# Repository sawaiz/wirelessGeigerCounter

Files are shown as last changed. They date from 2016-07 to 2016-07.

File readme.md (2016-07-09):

# Wireless Geiger Counter
A distributed radiation detection networks requires a low power, rugged, portable, and wireless detection modules. These prototypes are housed in a plastic shell allowing them to be made waterproof, transmit data over Wi-Fi allowing them to be placed anywhere you can host a network, and are designed to last for months from a single charge. A Geiger tube provides the signal that is read in by a microcontroller that then transmits the counts to a database.



## Hardware
A single board that hosts the electronics required to take power from a lithium ion cell, provide the bias voltage required by the Geiger tube (new old stock Russian SBM-20), and transmit that data over Wi-Fi.

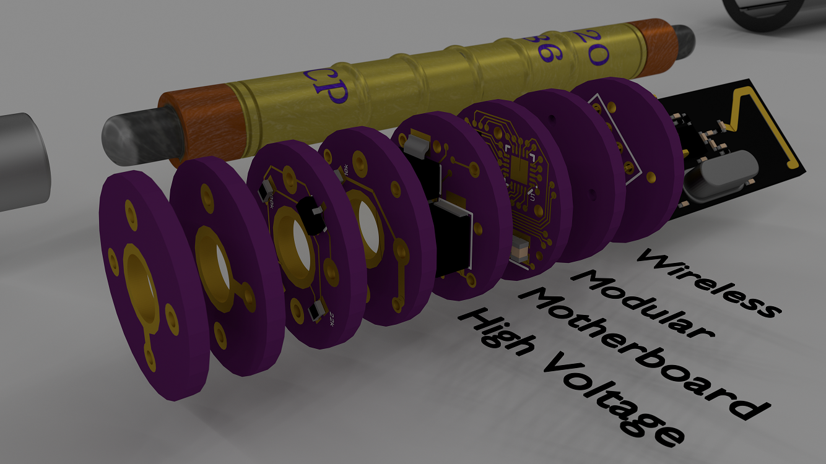
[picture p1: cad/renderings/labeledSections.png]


### Power
The power to the module is provided through a 18650 Li-ion chemistry cell. This is a rechargeable cell that is very common (used in laptop batteries, Tesla vehicles, and LED flashlights) with a capacity of 1.5Ah - 3.4Ah. The battery has a management circuit that prevents over/under voltage and allows charging. It also provides fuel gauging to the microcontroller. The rest of the board is supplied a regulated 3.3V.

### Wireless
The espressif module has a on board antenna although a chip antenna can be substituted. The Wi-Fi using the on board antennas on a ESP-12F module is shown to have a range of at least 250m with almost a km under ideal conditions. It is able to connect on 802.11 b/g/n with a maximum data rate of 150Mbps.

### Microcontroller
The ESP8266/ESP8285 has a integrated Tensilica L106 Diamond series 32-bit processor running at 80Mhz. The 12E/F module breaks out the 13 GPIO pins and one 10-bit ADC. Some of those pins are reserved for communication to storage, and wake from deep sleep. The pins are not 5V tolerant and average current consumption, including connection to Wi-Fi is 80mA, though peaks currents approach 500mA for short (<5ms) bursts.

### High voltage
The high voltage section is a Schmitt-trigger oscillator based boost converter feeding a Cockcroft-Walton voltage multiplier with the output divided and taken to a op-amp comparing against a voltage reference. The previous design used the microcontroller to boost the voltage, but that resulted in a 80mA constant current draw as the microcontroller could not be taken to deep sleep with the PWM running. The design was adapted from the following [application note](https://www.maximintegrated.com/en/app-notes/index.mvp/id/3757) form Maxim.

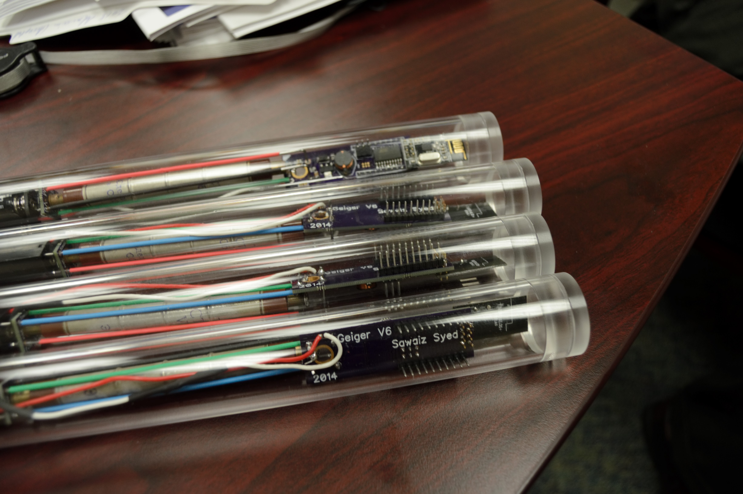
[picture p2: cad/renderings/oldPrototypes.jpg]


## Software
The software only resides on the microcontroller, and can be found [here](https://github.com/Sawaiz/geigerControl). The other required part is a SQL database to transmit the information to.

[oldPrototypes]: cad/renderings/oldPrototypes.jpg "Older prototypes"
[assembledTube]: cad/renderings/assembledTube.png "Fully Assembled Tube"
[labeledSections]: cad/renderings/labeledSections.png "Assembled Tube"

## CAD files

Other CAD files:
cad/Housing/Acrylic Tube Housing.dwg
3D/Inventor/.75in PVC.ipt
3D/Inventor/Housing/.75in PVC.ipt
Hardware/Transmitter 3D/Blender/Transmitter.blend
Hardware/Transmitter 3D/Inventor/Radiation Dector/.75in PVC.ipt
Transmitter 3D/Inventor/Radiation Dector/.75in PVC.ipt
cad/2.54 Breakaway/1x1.iam
cad/2.54 Breakaway/1x10.iam
cad/2.54 Breakaway/1x2 Angle.iam
cad/2.54 Breakaway/2x3.iam
cad/2.54 Breakaway/2x4.iam
cad/2.54 Breakaway/4x2 Angle.iam
cad/2.54 Breakaway/Holder.ipt
cad/2.54 Breakaway/OldVersions/1x2 Angle.0001.iam
cad/2.54 Breakaway/OldVersions/2x3.0001.iam
cad/2.54 Breakaway/OldVersions/Pin.0001.ipt
cad/2.54 Breakaway/OldVersions/PinRight1.0003.ipt
cad/2.54 Breakaway/OldVersions/PinRight2.0005.ipt
cad/2.54 Breakaway/Pin.ipt
cad/2.54 Breakaway/PinRight1.ipt
cad/2.54 Breakaway/PinRight2.ipt
cad/Housing/.75in PVC.ipt
cad/Housing/8907K48 045 Phosphate Rod.ipt
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

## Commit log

2014-04-12 Re-organaised and Consolidated from older repositories
    [Transmitter.blend]
2014-07-18 Reorganised software
    [Board.gbr, BoardOutline.gbr, Bottom.gbr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]
2014-07-19 organised 3d Model Folder
    [Transmitter.blend]
2014-07-24 Added BOM and Future Revisions
    [1x10.stp, BOM.xlsx]
2014-09-20 A lot of changes mostly new Board iterations.
    [BOM.xlsx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]
2014-10-15 I should be committing more frequently. Finally have a readme though.
    [BOM.xlsx]
2014-10-18 A lot of 3d work, No textures Yet.
    [0805 Resistor.0002.ipt, 0805 Resistor.ipt, 18650.ipt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]
2014-10-18 Raspberry Pi RX works, on first try, only explanation, witchery.
2014-10-19 Motherboard routed.
    [1x2 Angle.0001.iam, 1x2 Angle.iam, 4x2 Angle.iam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]
2014-10-20 Mk..7 Is born, 3d is done as well, BOM, coming soon.
    [.75in PVC.ipt, 10118194.ipt, DF40C(2.5)-20DS-0.4V.ipt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]
2014-10-28 Finalized 3d model, Organization, Presentation and poster.
    [2x4.iam, NRF24L01.ipt, NRF24L01P.ipt]
2015-02-17 TX and RX software for V6 finalised
    3d hardware models added for acrylic housing, rPiRx software, and 1975
    software for avr.
    [Acrylic Housing.0002.iam, Acrylic Housing.iam, Acrylic Tube Housing.0004.ipt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]
2015-09-09 Software moved to RadSens Repo https://github.com/aaronwoychek/RadSens
    [rPiRx.sdf]
2015-09-09 Deleted files, cleaning up
    [.75in PVC.ipt, 0805 Resistor.0002.ipt, 0805 Resistor.ipt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]
2015-09-09 Move hardware directory to root
    [.75in PVC.ipt, 0805 Resistor.0002.ipt, 0805 Resistor.ipt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]
2015-09-09 Cleaning up 3D folder
    [.75in PVC.ipt, 0805 Resistor.0002.ipt, 0805 Resistor.ipt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]
2015-09-09 Datasheets folder removed, approprate datasheed will be added to specific PCB folder
2015-09-09 Cleaned inventor folder
    [.75in PVC.ipt, 0805 Resistor.0002.ipt, 0805 Resistor.ipt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]
2015-09-09 Removed all older versions
    [1x10.stp, BOM.xlsx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]
2015-09-09 Removed some gerbers
    [Board Outline.gbr, Board.gbr, Bottom Assy.gbr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]
2015-09-09 Renaming and organising files for deltetion
    [Board.gbr, BoardOutline.gbr, Bottom.gbr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]
2015-09-09 Move V6 out
    [bom.xlsx]
2015-09-09 Removed V6
    [bom.xlsx]
2015-09-09 Made V7 pcb main pcb
    [bom.xlsx]
2015-09-09 Renamed to lower case
    [bom.xlsx]
2015-09-09 Lowercase folder names
    [.75in PVC.ipt, 0805 Resistor.ipt, 10118194.ipt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]
2015-09-09 Lowercase cad folder
    [.75in PVC.ipt, 0805 Resistor.ipt, 10118194.ipt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]
2016-06-27 Deleted all code, moved ot geiger control repo
    [bom.xlsx]
2016-06-27 Updated Schematic
2016-07-09 Added readme, still needs pictures
    [.75in PVC.ipt, 0805 Resistor.ipt, 10118194.ipt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]
2016-07-09 Deleted all the imported files
    [0805 Resistor.ipt, 10118194.ipt, 18650.ipt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]
